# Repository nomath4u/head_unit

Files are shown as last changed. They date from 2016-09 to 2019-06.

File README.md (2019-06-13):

# Custom Bluetooth Headunit

## Summary

The idea behind this project is to get a lightweight bluetooth stereo
into any car. The amount of exposed unit will be customizable (If you want a
screen on it you will want to be able to see it). But should be able to function
with only the microphone showing, allowing the rest of the DIN area to be used 
for other things

##Included in this repository

As I work on this project I will be adding additional thing. For now there is
only the INO file in order to program the microcontroller that will be used 
with the unit. As well as a tool to help send commands to the rn-52. Eventually there will be a wiring diagram for prototyping with
a parts list and then an eagle schematic and parts list so the board can be
ordered and then put together and reflowed. After that, separate STL files for 
parts that will need to be 3d printed will be added based on common
configurations.

## Bugs in V1.0
CMD enable is wired to GPIO10 instead of 9
USBD- is not wired at all
Power input is not exposed

## Bugs in V1.1
Still yet to be discovered

## Proposed Configurations

## Schematic
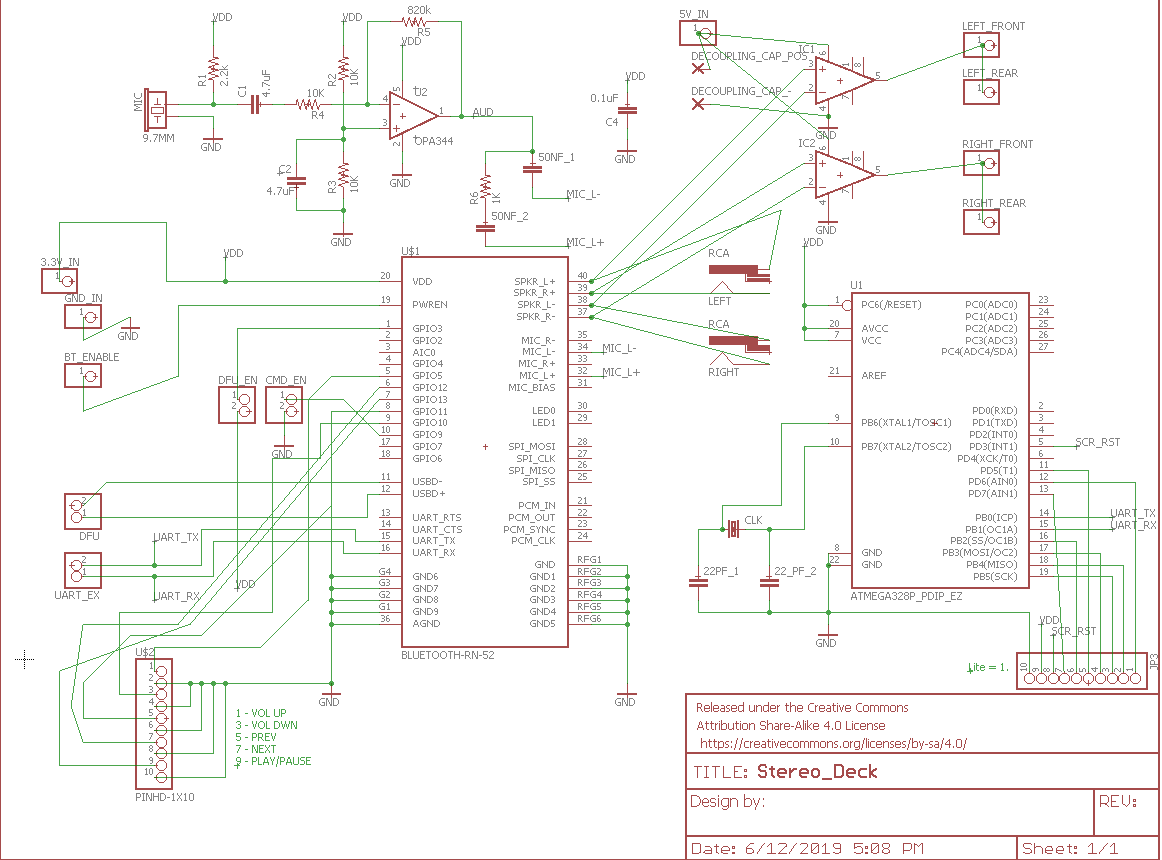
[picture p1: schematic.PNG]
schematic Schematic


### Minimal

In the minimal configuration only the microphone will be exposed. The board 
will be mounted on the back of any 3d printed part with only a hole for the
microphone and no buttons will be broken out. In this configuration everything
will need to be controlled from the phone

### Standard

In this configuration we have the same setup as the Minimal except with buttons
broken out for play/pause, next/previous track, and a few other buttons.

### Large

In this configuration a screen is involved. On this creen the Title, artist,
and album name of the song will displayed as well as a customizable background.
This is implemented with a SPI TFT screen. There are many different sizes
available from adafruit so as requests are made different STL files and code
defines will have to be made in order to accomodate the different screens

##NOTE

* You will want an amplifier for this to be in normal volume range. There is a 
preamplifier on the bluetooth part but without an amplifier you won't be able
to hear it when at highway speeds. As of V1.1 There are spaces for 2 LM386s which help. It may be loud enough on its own for you if you use those connections.

## Useful setup tips
Update to version 1.16 first. Many settings don't work as expected without doing that
Use the added uart_via_arduino code in order to relay commands through an arduino
to the RN-52. Make sure your arduino is @ 3.3V.

Commands I liked
S%,86 // Enableds reconnect on power-on, discoverable on startup, and disables system tones
SN,<name_here> //Name your device.
SS,0F //Turn up the internal amplifier to the max (may want to use something different depending on your amp

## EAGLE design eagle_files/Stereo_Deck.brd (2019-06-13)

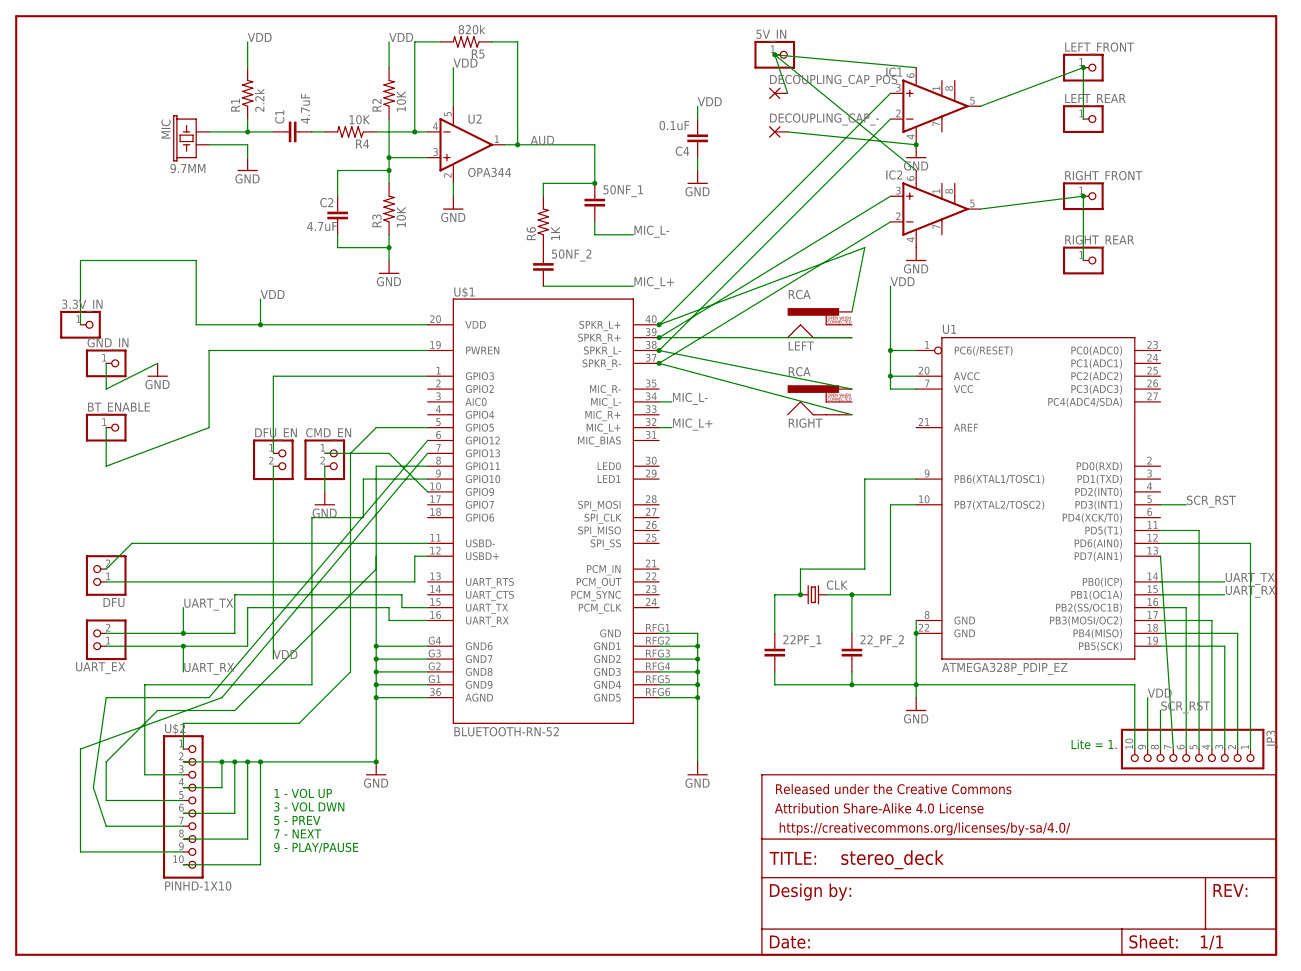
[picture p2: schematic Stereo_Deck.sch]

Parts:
3.3V_IN, 5V_IN: PINHD-1X1; 1X01
22PF_1, 22_PF_2, 50NF_1, 50NF_2: CC0603; C0603
BT_ENABLE: PINHD-1X1; 1X01
C1, C2: 4.7uF; 0603-CAP
C4: 0.1uF; 0603-CAP
CLK: CRYSTALHC49US; HC49US
CMD_EN: PINHD-1X2; 1X02
DECOUPLING_CAP_-: 2,15/1,0
DECOUPLING_CAP_POS: 2,15/1,0
DFU: PINHD-1X2; 1X02
DFU_EN: PINHD-1X2; 1X02
FRAME1: FRAME-LETTER; CREATIVE_COMMONS
GND_IN: PINHD-1X1; 1X01
IC1, IC2: LM386N-1; DIL08
JP3: PINHD-1X10; 1X10
LEFT: RCA
LEFT_FRONT: PINHD-1X1; 1X01
LEFT_REAR: PINHD-1X1; 1X01
MIC: 9.7MM; MIC-9.7MM
R1: 2.2k; 0603-RES
R2, R3, R4: 10K; 0603-RES
R5: 820k; 0603-RES
R6: 1K; 0603-RES
RIGHT: RCA
RIGHT_FRONT: PINHD-1X1; 1X01
RIGHT_REAR: PINHD-1X1; 1X01
U1: ATMEGA328P_PDIP_EZ; DIL28-EZ
U2: OPA344; SOT23-5
U$1: BLUETOOTH-RN-52; RN-52
U$2: PINHD-1X10; 1X10-BIG
UART_EX: PINHD-1X2; 1X02

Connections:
AUD: 50NF_1.1, R5.1, R6.2, U2.1 (OUT)
CMD_EN: CMD_EN.1, U$1.10 (GPIO9)
DFU_EN: DFU_EN.1, U$1.1 (GPIO3)
GND: 22PF_1.2, 22_PF_2.2, C2.2, C4.1, CMD_EN.2, DECOUPLING_CAP_-.1, GND_IN.1, IC1.4 (GND), IC2.4 (GND), JP3.10, MIC.2, R3.1, U1.8 (GND), U1.22 (GND), U2.2 (V-), U$1.36 (AGND), U$1.G1 (GND9), U$1.G2 (GND8), U$1.G3 (GND7), U$1.G4 (GND6), U$1.RFG1 (GND), U$1.RFG2 (GND1), U$1.RFG3 (GND2), U$1.RFG4 (GND3), U$1.RFG5 (GND4), U$1.RFG6 (GND5), U$2.2, U$2.4, U$2.6, U$2.8, U$2.10
MIC_L+: 50NF_2.2, U$1.32 (MIC_L+)
MIC_L-: 50NF_1.2, U$1.34 (MIC_L-)
unnamed: 22PF_1.1, CLK.1, U1.9 (PB6(XTAL1/TOSC1))
unnamed: JP3.1, U1.12 (PD6(AIN0))
unnamed: JP3.2, U1.18 (PB4(MISO))
unnamed: IC1.3 (+IN), LEFT.PIN, U$1.40 (SPKR_L+)
unnamed: IC2.3 (+IN), LEFT.SHELL, U$1.39 (SPKR_R+)
unnamed: IC1.2 (-IN), RIGHT.PIN, U$1.38 (SPKR_L-)
unnamed: DFU.2, U$1.11 (USBD-)
unnamed: DFU.1, U$1.12 (USBD+)
unnamed: BT_ENABLE.1, U$1.19 (PWREN)
unnamed: JP3.3, U1.19 (PB5(SCK))
unnamed: JP3.4, U1.17 (PB3(MOSI/OC2))
unnamed: JP3.5, U1.11 (PD5(T1))
unnamed: JP3.6, U1.16 (PB2(SS/OC1B))
unnamed: JP3.7, U1.13 (PD7(AIN1))
unnamed: 22_PF_2.1, CLK.2, U1.10 (PB7(XTAL2/TOSC2))
unnamed: C1.1, MIC.1, R1.1
unnamed: IC2.2 (-IN), RIGHT.SHELL, U$1.37 (SPKR_R-)
unnamed: R4.1, R5.2, U2.4 (-IN)
unnamed: C1.2, R4.2
unnamed: C2.1, R2.1, R3.2, U2.3 (+IN)
unnamed: 50NF_2.1, R6.1
unnamed: 5V_IN.1, DECOUPLING_CAP_POS.1, IC1.6 (VS), IC2.6 (VS)
unnamed: U$1.5 (GPIO5), U$2.1
unnamed: U$1.9 (GPIO10), U$2.3
unnamed: U$1.8 (GPIO11), U$2.5
unnamed: U$1.6 (GPIO12), U$2.7
unnamed: U$1.7 (GPIO13), U$2.9
unnamed: IC2.5 (OUT), RIGHT_FRONT.1, RIGHT_REAR.1
unnamed: IC1.5 (OUT), LEFT_FRONT.1, LEFT_REAR.1
SCR_RST: JP3.8, U1.5 (PD3(INT1))
UART_RX: U1.15 (PB1(OC1A)), U$1.16 (UART_RX), UART_EX.1
UART_TX: U1.14 (PB0(ICP)), U$1.15 (UART_TX), UART_EX.2
VDD: 3.3V_IN.1, C4.2, JP3.9, R1.2, R2.2, U1.1 (PC6(/RESET)), U1.7 (VCC), U1.20 (AVCC), U2.5 (V+), U$1.20 (VDD)

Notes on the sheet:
Lite = 1.
1 - VOL UP 3 - VOL DWN 5 - PREV 7 - NEXT 9 - PLAY/PAUSE

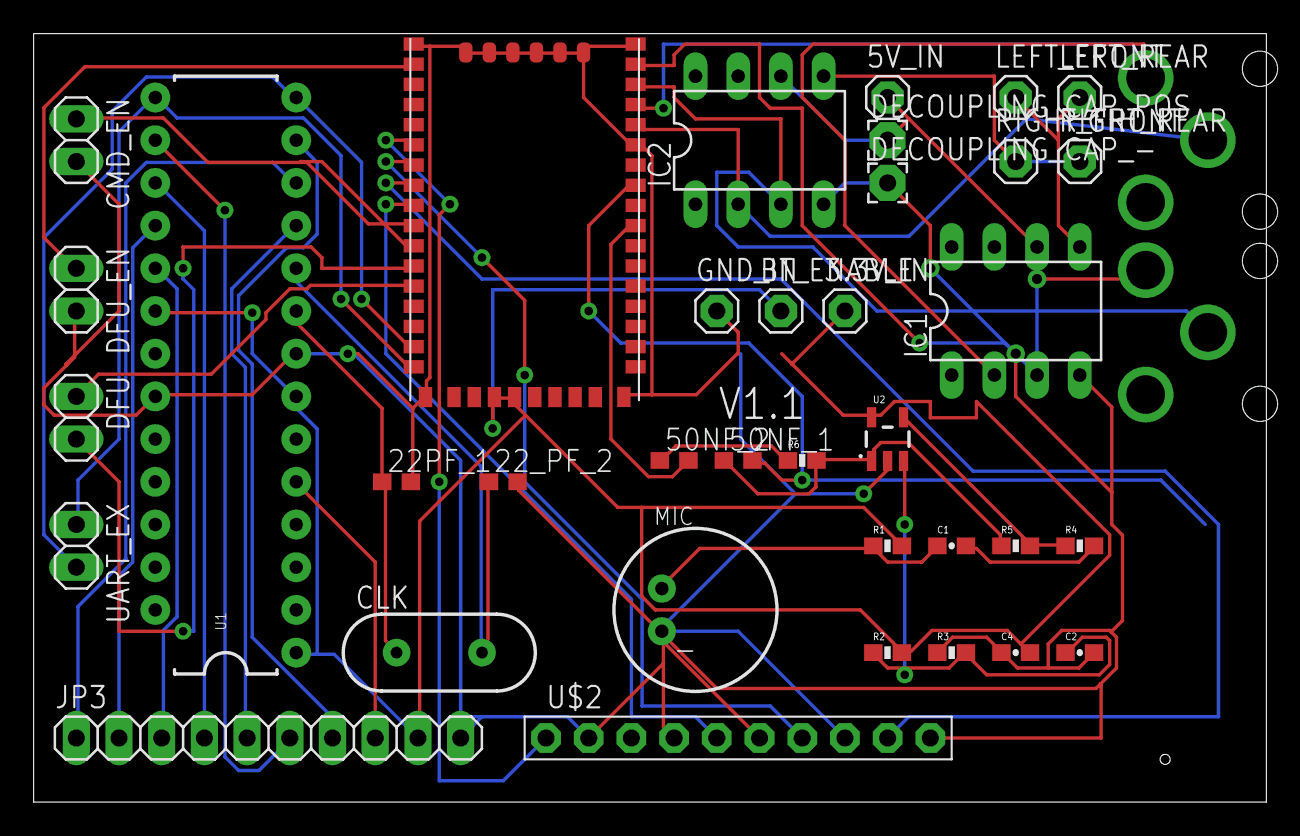
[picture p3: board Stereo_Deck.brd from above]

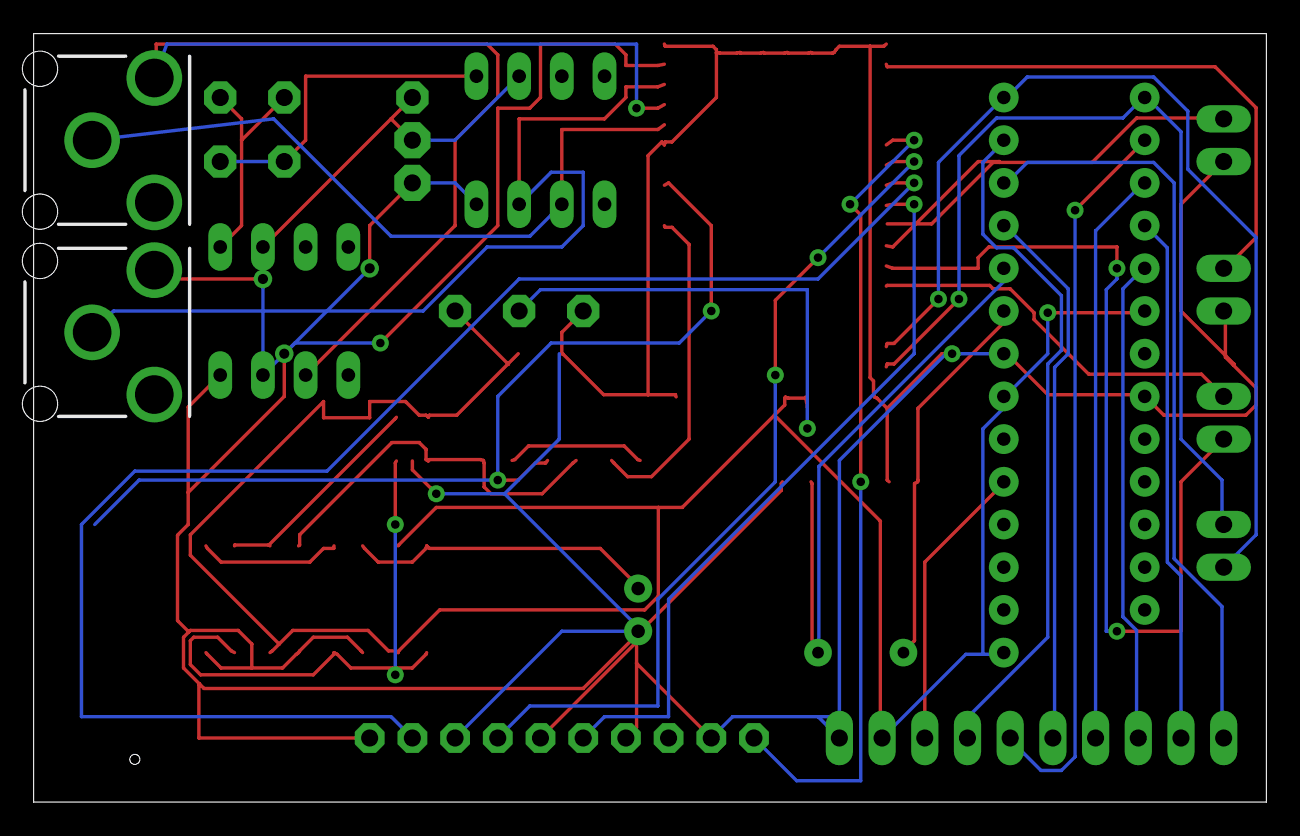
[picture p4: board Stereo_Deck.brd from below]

Board: 2 copper layers, 73.3 x 45.7 mm, 39 parts (2 on the bottom side), 39 nets.

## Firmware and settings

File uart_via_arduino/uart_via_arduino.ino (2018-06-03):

#include <SoftwareSerial.h>
SoftwareSerial rn_serial(D7,D6);
void setup() {
  Serial.begin(115200);
  //Serial1.begin(115200);
  rn_serial.begin(115200);
  while(!Serial){;}
  Serial.println("Ready to go Serial");
}

void loop() {
  if(Serial.available() > 0){
    //Serial.println("Printing something");
    rn_serial.write(Serial.read());
  }
  if(rn_serial.available() > 0){
    //Serial.println("Receiving something");
    Serial.write(rn_serial.read());
  }
}

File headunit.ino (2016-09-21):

#include <Adafruit_GFX.h>

#include <Adafruit_ST7735.h>
#include <SPI.h>


/*Defines for the 1.8" TFT from adafruit working on a Teensy 3.1 
with hardware SPI in normal configuration*/
#define TFT_CS     6
#define TFT_RST    1  
#define TFT_DC     12
Adafruit_ST7735 tft = Adafruit_ST7735(TFT_CS,  TFT_DC, TFT_RST);


#define STRLEN 400

float p = 3.1415926;
void setup(void) {
  Serial.begin(9600);
  Serial2.begin(115200);
  Serial.print("Hello! ST7735 TFT Test");

  // Use this initializer if you're using a 1.8" TFT
  tft.initR(INITR_BLACKTAB);   // initialize a ST7735S chip, black tab
  tft.setRotation(1);

  Serial.println("Initialized");

  uint16_t time = millis();
  tft.fillScreen(ST7735_BLACK);
  time = millis() - time;

  Serial.println(time, DEC);
  delay(500);

  // large block of text
  tft.fillScreen(ST7735_BLACK);
  /*Once this is working try what is in the print test*/
  testdrawtext("No song available yet ", ST7735_WHITE);
  delay(1000);

}

void loop() {
  int i =0;
  int complete = 0;
  int timer = 0;
  char str[STRLEN] = {'\0'};
  String data = "";
  //Clear out anything from before
  while(Serial2.available()){
    char c = Serial2.read();
  }
  Serial2.print("AD\r"); //Get metadata
  delay(100); //Let the command be processed switch to a while loop waiting on available in the future
  /*Get all the metadata*/
  while( complete < 7){
    if(Serial2.available()){
      char c = Serial2.read();
      data += c;
      timer = millis();
      i++;
      if(c == '\n'){
        complete++;
      }
    }
    if ((millis() - timer) > 500){ //Could take up to 500 ms for the BT part
                                   //To have new data on serial
      complete++;
    }
  }
  tft.fillScreen(ST7735_BLACK);
  data.toCharArray(str,i);
  testdrawtext(str,ST7735_WHITE);
  delay(1000); //Check for new song every second
}

void testdrawtext(char *text, uint16_t color) {
  tft.setCursor(0, 0);
  tft.setTextColor(color);
  tft.setTextWrap(true);
  tft.print(text);
}

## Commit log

2016-09-21 Cleaned up old commented out code that won't be used anymore. Also added ideas for speed improvements
    [headunit.ino]
2018-06-03 Updated with more information now that I have tired the external communications exposures
2019-06-13 Added hopefully only necessary eagle files to reproduce?
    [Stereo_Deck.brd, Stereo_Deck.sch]
2019-06-13 Updated silkscreen for new board version
    [Stereo_Deck.brd]
2019-06-13 Add picture of the schematic (hopefully

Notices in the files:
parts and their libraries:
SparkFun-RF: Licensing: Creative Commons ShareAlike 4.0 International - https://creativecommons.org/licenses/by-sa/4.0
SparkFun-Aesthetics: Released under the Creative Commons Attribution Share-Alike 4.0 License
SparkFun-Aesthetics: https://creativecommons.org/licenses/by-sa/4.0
